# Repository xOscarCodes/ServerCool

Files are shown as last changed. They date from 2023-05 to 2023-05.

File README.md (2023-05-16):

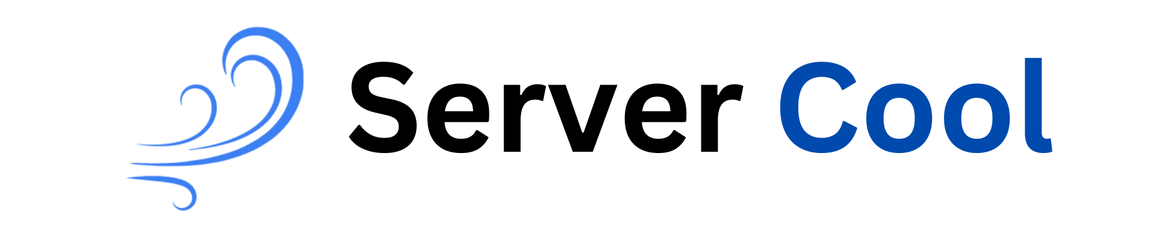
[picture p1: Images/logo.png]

# Server Cool
<p align="justify">The ServerCool interface offers a wide range of functionalities to users, who must authenticate themselves on the login page to gain access. Unauthorized use restricted from accessing information or controlling any features. One notable feature is the ability to monitor real-time temperature readings of both the server rooms and air conditioners on a single page, promoting transparency.</p>
<p align="justify">The platform also provides statistical analysis capabilities, offering line, bar, and area charts for analyzing past data. Furthermore, users can export the data in their desired format. All user actions are logged in the Audit logs, ensuring accountability and tracking.</p>
<p align="justify">A notable feature is the software's capability to switch between manual and automatic configuration. This is achieved through the utilization of neural networks for system automation. Specifically, a feedforward fully connected neural network, also known as a multi-layer perceptron (MLP), is trained to predict air conditioner temperature and fan speed based on the current room temperature. The predictions are updated every 10 minutes and published on MQTT to the designated node. Additionally, the neural network is retrained every 24 hours.</p>
<p align="justify">The MLP consists of four layers: three hidden layers and one output layer. The hidden layers employ the rectified linear unit (ReLU) as the activation function, while the output layer utilizes linear activation. The network is trained using mean squared error (MSE) loss and the Adam optimizer. This type of neural network is powerful and versatile, capable of learning complex non-linear relationships between input and output data.</p>
<p align="justify">To ensure data privacy, the audit logs, which contain the login information of users, are automatically removed from the database and the interface on the 21st of every month.</p>
<p align="justify">Another feature allows users to decode infrared (IR) signals from an air conditioner remote using an IR receiver and store the dataset in the Node. These stored signals can then be transmitted to the air conditioner's IR receiver, enabling users to activate specific commands. The transmission frequency can be adjusted to accommodate various appliances. This functionality provides a convenient and efficient method for remotely controlling the air conditioning system and managing the server room's temperature.</p>

#### Deployment Documentation: [Deployment](./Documentation/Documentation.md)

## Tech Stack
### Front-end
- HTML
- CSS
- EJS
- SCSS
- Highcharts
- Bootstrap

### Back-end
- Node js
- Express
- MongoDB

### Hardware
- ESP32
- DS18B20 Waterproof Digital Thermometer Sensor Probe
- Hi-Link 5V 0.6A AC-DC Power Converter
- Hi-Link 12V 5W Power Module
- Original JHD 20Ã—4 character LCD Display with Blue Backlight
- 12V Police Siren
- TSOP 1838B small
- IR Blaster
- ENC28J60 Ethernet LAN Module
- 5 Volt Relay 
- BC547 Transistor 
- LEDs - RED and GREEN

### Automation
- Python

### Other
- Docker
- Mosquito MQTT

## License
[MIT](https://choosealicense.com/licenses/mit/)

## Authors
- [@xOscarCodes](https://github.com/xOscarCodes)
- [@Aadi3333](https://github.com/Aadi3333)
- [@harshdeep-s](https://github.com/harshdeep-s)
- [@ishaan2307](https://github.com/ishaan2307)
- [@kanishkjain0263](https://github.com/kanishkjain0263)
- [@XQuestCode](https://github.com/XQuestCode)
- [@Yohjit-2910](https://github.com/Yohjit-2910)

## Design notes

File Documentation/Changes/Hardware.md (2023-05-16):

**Git clone the entire repository**
```bash
git clone https://github.com/xOscarCodes/ServerCool.git
```

**Change directory**
```bash
cd /ESP/ServerProject/src
```

**Change `ID` and `LOC`**
```c++
const String nodeId = "ID";
const String location = "LOC";
```

**Change IP Address**
```c++
String domain_name_str = "<MQTT-BROKER-IP-ADDRESS>";
```

Replace `<MQTT-BROKER-IP-ADDRESS>` with IP Address of MQTT Broker

**Change username and password**
```c++
  while (!client.connect("serverESP32", "<USERNAME>", "<PASSWORD>"))
  {
    Serial.print(".");
    Ethernet.init(5);
    if (Ethernet.begin(mac) == 0)
    {
      Serial.println("Failed");
    }
    Serial.print("IP Address   : ");
    Serial.println(Ethernet.localIP());
  }
```

Replace `<USERNAME>` and `<PASSWORD>` with correct MQTT credentials.

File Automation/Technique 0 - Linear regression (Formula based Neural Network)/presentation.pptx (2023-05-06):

## Machine Learning Algorithms :

(whatever I learnt in past 3 weeks)
BY- DEVYASH PARIHAR
2016A7PS0066P

## Regression: 1).Linear Regression 2).Polynomial Regression Classification: 1).Logistic Regression 2).K-Nearest Neighbors(K-NN) 3).Support Vector Machine

## Linear Regression:

- Simple linear regression is useful for finding relationship between two continuous variables. One is predictor or independent variable and other is response or dependent variable.
- Examples:
a).Years of Experience vs Salary
b). Nos of hours studied vs Marks obtained.

## Sample dataset:

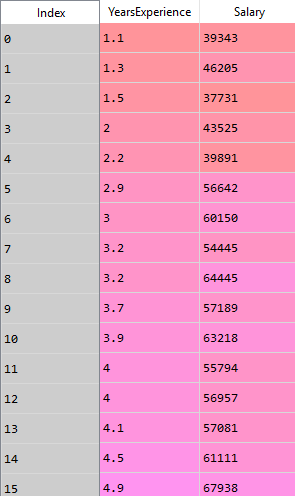
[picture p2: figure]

## Plotting the training set, we obtain a straight line in case of simple linear regression as shown below.

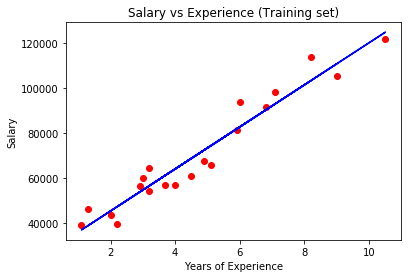
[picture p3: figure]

## Polynomial Regression:

- Polynomial regression is a form of regression analysis in which the relationship between the independent variable x and the dependent variable y is modelled as an nth degree polynomial in x.
- The kth order polynomial model in one variable is given by
y=a0 + a1*x + a2*x*x + a3*x*x*x + ……… (ak)*(x^k)

## Sample dataset:

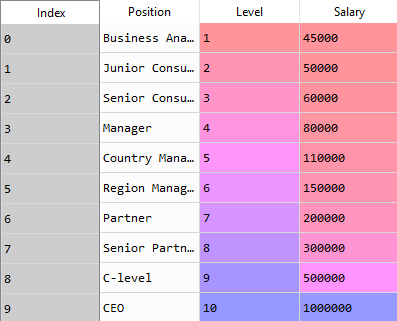
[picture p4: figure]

## Curve fits the dataset very precisely here in the case of polynomial regression.

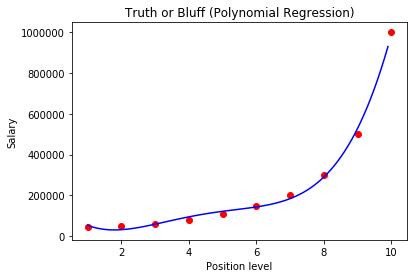
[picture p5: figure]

## Logistic Regression:

- It is the go-to method for binary classification problems (problems with two class values).
- The two possible dependent variable values are often labelled as "0" and "1", which represent outcomes such as pass/fail, win/lose, alive/dead or healthy/sick.

## Sample dataset:

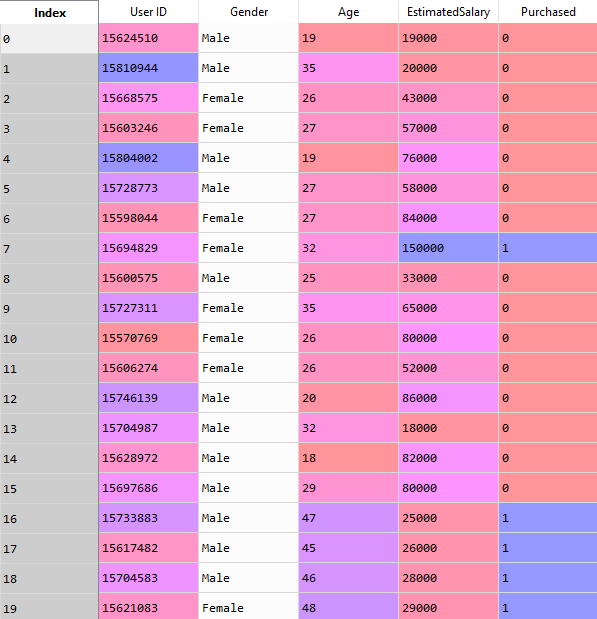
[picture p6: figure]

## Two separate regions got formed.

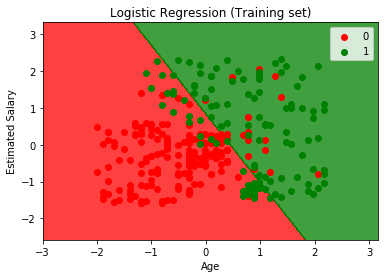
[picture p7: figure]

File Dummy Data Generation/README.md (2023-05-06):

# Generate Dummy Data
---
This directory includes the files to generated dummy data for testing.

## Changing 'COM Port' and 'Baud Rate'
---
#### Cloning the repo
```bash 
git clone https://github.com/xOscarCodes/IoT-Application-Development.git
```

#### Open two terminals and Change to the directory to 'Dummy Data Generation' directory 
```bash
cd .\IoT-Application-Development\
```

#### Command in Terminal 2
```bash
cd .\arduino\
```

#### Open any code editor 
```bash
code .
```

#### Make changes to the code
Change `path`  and `baudeRate` value to change `COM PORT` and `Baud Rate`  
```javascript
const port = new SerialPort({
    path: 'COM4',   // Change the COM port as required 
    baudRate: 9600  // Change the Baude Rate as required
})
```

Make sure that the bade rate matches with the baud rate from the Arduino code
```c++
	Serial.begin(9600);
```

## Run Locally
---

#### Open two terminals and Change to the directory to 'Dummy Data Generation' directory 
```bash
cd .\IoT-Application-Development\
```

```bash
cd '.\Dummy Data Generation\'
```
 
##### Command in Terminal 1
```bash
cd .\MQTT-API\
```

###### Start the server
```bash 
npm start
```

##### Command in Terminal 2
```bash
cd .\arduino\
```

###### Start the server
```bash
npm start
```

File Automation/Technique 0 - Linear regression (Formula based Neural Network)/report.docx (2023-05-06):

# PART 1:

# INTRODUCTION TO IDS INFOTECH:

Established in 1989, IDS Infotech Ltd. (IDS), has been a preferred Business Process Management and Software Solution provider to Fortune 500 companies and AM100 law firms worldwide for over two decades. A team of over 1,000 trained and skilled professionals, work round-the-clock to deliver quality solutions such as patent research and analytics, technology solutions, content management, engineering design and manufacturing support, physician practice management, eDiscovery and paralegal support, technical help-desk and other industry specific back-office processes. With various delivery centers in North India, IDS has multiple front-end offices globally, including US, UK and the Netherlands.

Legal Services- IDS- Legal has been a worldwide leader in providing legal support services since 1999. We provide Fortune 1000 companies and AM250 Law Firms with an elite group of professionals providing e-Discovery and Paralegal services. (http://www.ids-legal.com/)

Engineering Services- Inde Dutch Engineering & Aerospace Services Limited ("IDEAS"), an AS9100 Rev D certified company, is a leading engineering solutions provider catering to customers in the Aerospace, Semiconductors, Automotive, Machinery, and Affiliated Industry segments. (http://www.ideasengg.com/)

Software Services- With a team of 100+ Software Engineers, IDS provides its customers with customized software solutions, supporting the end to end cycle of product development. We offer an exceedingly productive fusion of business and technological expertise utilizing our in-house domain experts. (http://ids-technologies.in/)

Content Publishing And Management Service - The Content Management and Publishing Services Group (CMPSG) at IDS Infotech Ltd., specializes in delivering customized, technology driven data capture, data conversion, e-publishing, pre press and editorial solutions. (http://cmp.idsil.com/)

Patent Research And Analytics- IDS-IP offers a suite of Patent Research and Analytics Services in creation, protection and monetization of patent rights. Our processes are specially designed and tailored to provide patent protection. (http://www.ids-ip.com/)

HealthCare Services- IDS-Healthcare is a specialized team of professionals providing a gamut of Healthcare services to Hospitals, CROs, Medical Management Companies, Insurance providers, etc. worldwide. (http://www.idsargus.com/)

Environment Health And Safety Services- IDS has been providing (M)SDS services to Environment, Health and Safety (EH&S) compliance and information management services companies in USA and Canada for over eight years. (http://idsil.com/environment.php)

Medical Scribe- At IDS, we offer virtual scribe services to US doctors with marvels of technology to stream live patient visits to our HIPAA compliant facilities , whereby IDS Medical Scribes undertake real time updates of US hospital EHRs. (https://medicalscribe.idsil.com/)

# PART 2:

# SUPERVISED MACHINE LEARNING:

1). Regression:

a). Simple Linear Regression- Simple linear regression is useful for finding relationship between two continuous variables. One is predictor or independent variable and other is response or dependent variable.

- Example:


(Years of Experience vs Salary dataset)


(Plotting the training set)

b). Polynomial Regression- Polynomial regression is a form of regression analysis in which the relationship between the independent variable x and the dependent variable y is modelled as a nth degree polynomial in x.

The kth order polynomial model in one variable is given by

y=a0 + a1*x + a2*x*x + a3*x*x*x + ……… (ak)*(x^k)

Consider the dataset given below.


Curve fits the dataset very precisely here in the case of polynomial regression.


2). Classification:

a). Logistic Regression- It is the go-to method for binary classification problems (problems with two class values).

The two possible dependent variable values are often labelled as "0" and "1", which represent outcomes such as pass/fail, win/lose, alive/dead or healthy/sick.


The above dataset is used to make the machine learn and thus to predict whether a customer is going to buy the product or not based on the variables such as his/her salary, age etc.


So, two separate regions got classified. However not all the predictions are correct as some of the green points are in the red region while some of the red points are in green region. Still, it’s a good model to predict whether the customer is going to buy the product or not.

b). K-Nearest Neighbors(K-NN)- KNN is a non-parametric, lazy learning algorithm. Its purpose is to use a database in which the data points are separated into several classes to predict the classification of a new sample point.

We are going to plot the previous dataset using this algorithm this time.

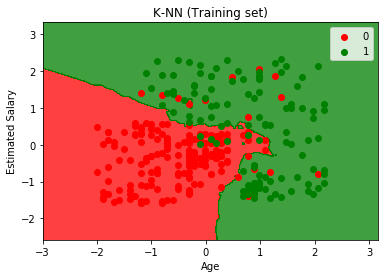
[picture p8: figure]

This time the boundary is not a straight line as it was in logistic regression and therefore it is more accurate in predicting the dependent variable.

c). Support Vector Machine- A Support Vector Machine (SVM) is a discriminative classifier formally defined by a separating hyperplane. In other words, given labeled training data (supervised learning), the algorithm outputs an optimal hyperplane which categorizes new examples. In two-dimensional space this hyperplane is a line dividing a plane in two parts where in each class lay in either side.

We are again using the earlier dataset to see how this algorithm predicts or performs in comparison to others.

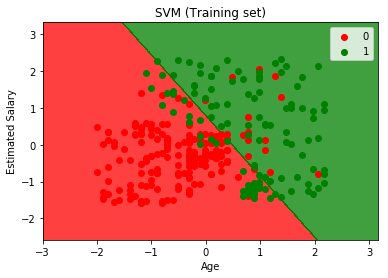
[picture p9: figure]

It also makes a line dividing the plane in two regions just like the logistic regression. However, in the case of logistic regression the decision boundary needs not to be a straight line always. Its shape can vary.

# PART 3:

# ANALYSIS OF TEMPERATURE AND HUMIDITY AT COMPANY’S OFFICE OF LAST TWO YEARS:

INTRODUCTION:

We have been shared a file that contains each day’s temperature and humidity entries at the company’s office for the last 2 years and we are supposed to find or establish a relationship between the temperature/humidity and the time of the day it was recorded at. Here is a sample of the dataset we had been given. It has the following variable as columns:

a) ID
b) Temperature
c) Humidity
d) Date and time

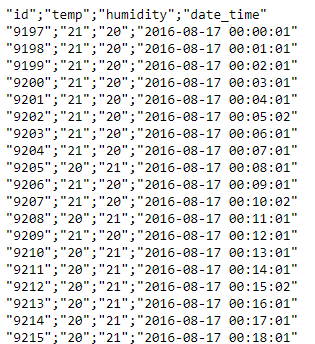
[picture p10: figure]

PROGRESS:

Till now, we have done the data preprocessing part completely. i.e. we made a table with the above listed variables as its columns.

The next thing we need to do is to make a model using one of the various machine learning algorithms so as to find the relationship if there exists any. Attached below is the preprocessed data in the form of a table.

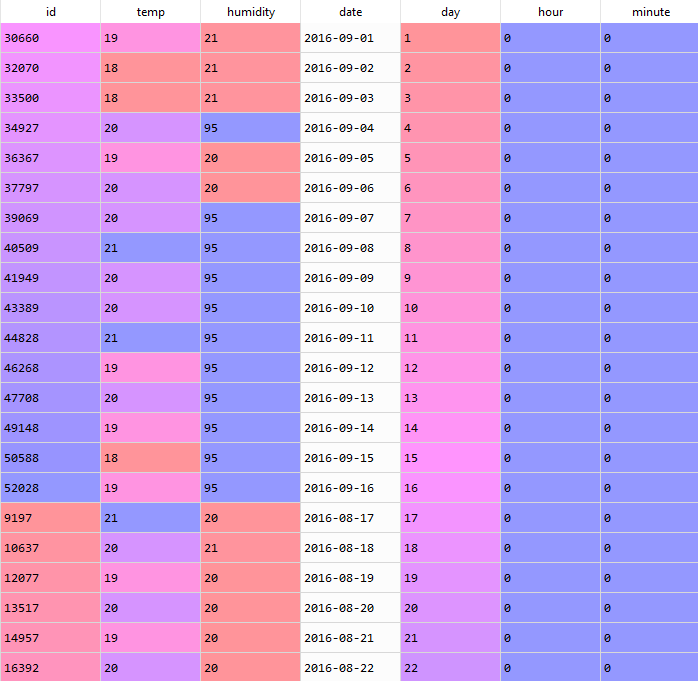
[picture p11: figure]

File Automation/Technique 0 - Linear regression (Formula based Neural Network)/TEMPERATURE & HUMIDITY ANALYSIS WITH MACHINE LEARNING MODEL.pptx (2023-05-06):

## TEMPERATURE & HUMIDITY ANALYSIS WITH MACHINE LEARNING MODEL

UNDER GUIDANCE OF: MR JAY RAM SINGH (TECHNICAL TEAM MANAGER)
MS DEEPTI KUMARI (HR AT CHANDIGARH CENTER)
MS AMRITA KAPOOR BEDI (ASSISTANT MANAGER HR,CORPORATE)
BY: DEVYASH PARIHAR (2016A7PS0066P)
SAI PUNEETH (2016A7PS0059H)

## PROJECT DESCRIPTION

DATASET:

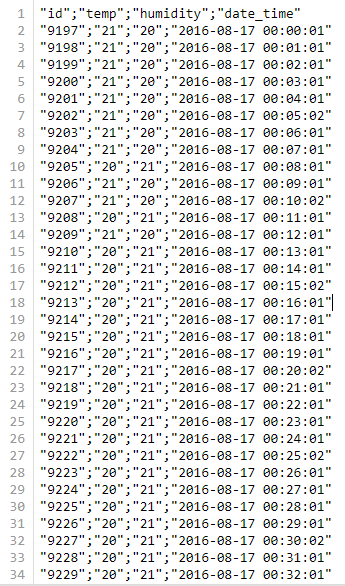
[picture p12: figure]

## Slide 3

- The dataset has 8,21,692 rows.
- Contains each minute’s temperature and humidity recordings at Mohali’s server room.
- Ranges from 2016-08-17 to 2018-05-24.
- What can we obtain from this data ? (Objective)

## Data preprocessing:

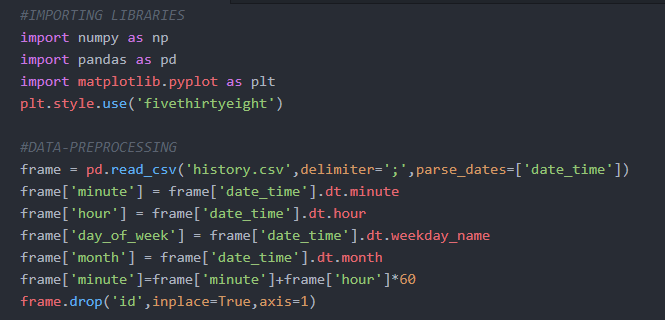
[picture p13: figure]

## DATAFRAME:

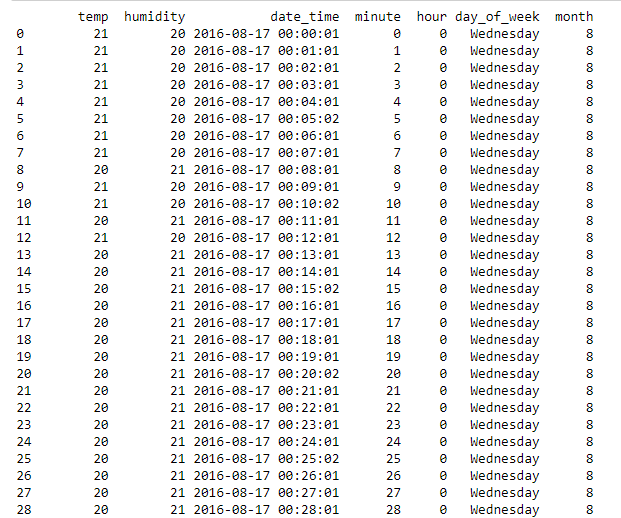
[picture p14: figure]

## Temp vs time of the day graph for the first day of the dataset :

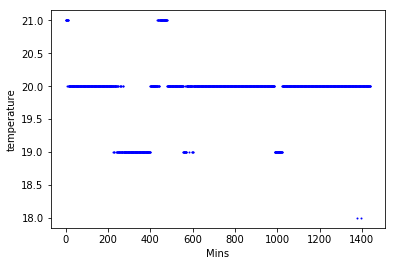
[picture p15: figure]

## Temp vs time of the day graph for the second day of the dataset :

## MAKING SEPARATE DATAFRAMES FOR DIFFERENT DAYS OF A WEEK:

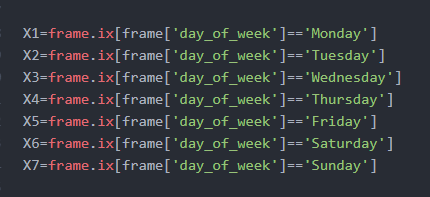
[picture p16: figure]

## X1 :

## Plotting avg Temp vs time of the day for different days of the week:

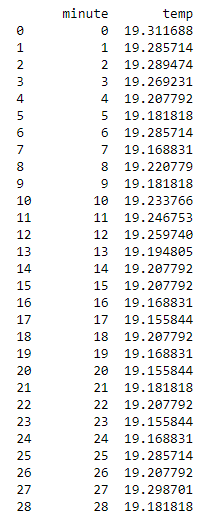
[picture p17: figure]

## Monday:

## Tuesday:

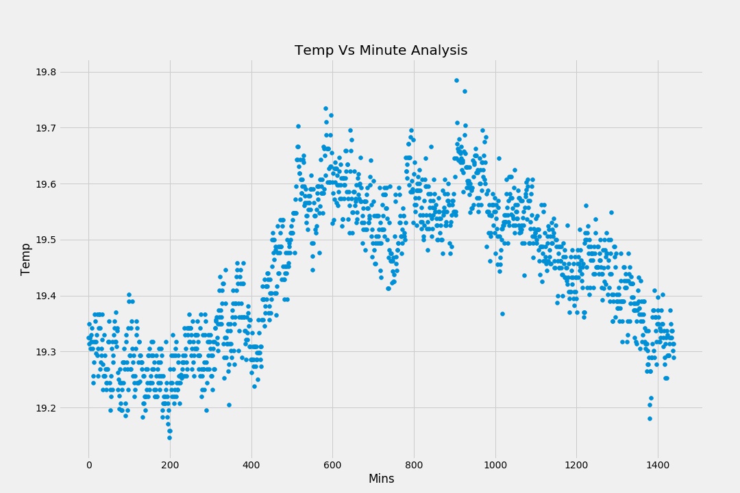
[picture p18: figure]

## Wednesday:

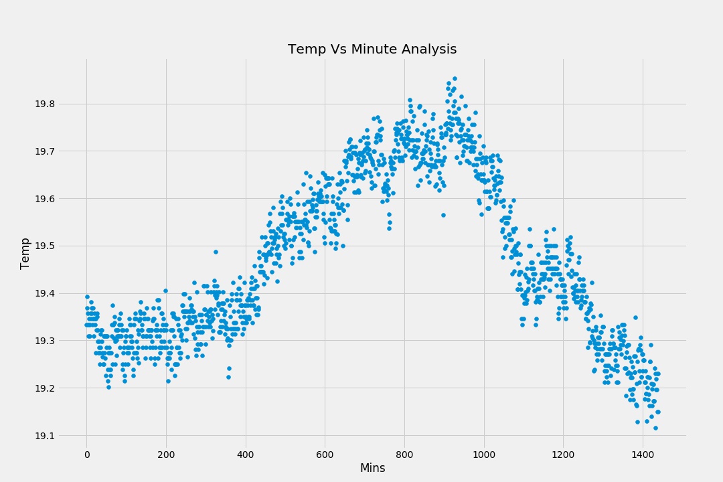
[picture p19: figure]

## Thursday:

## Friday:

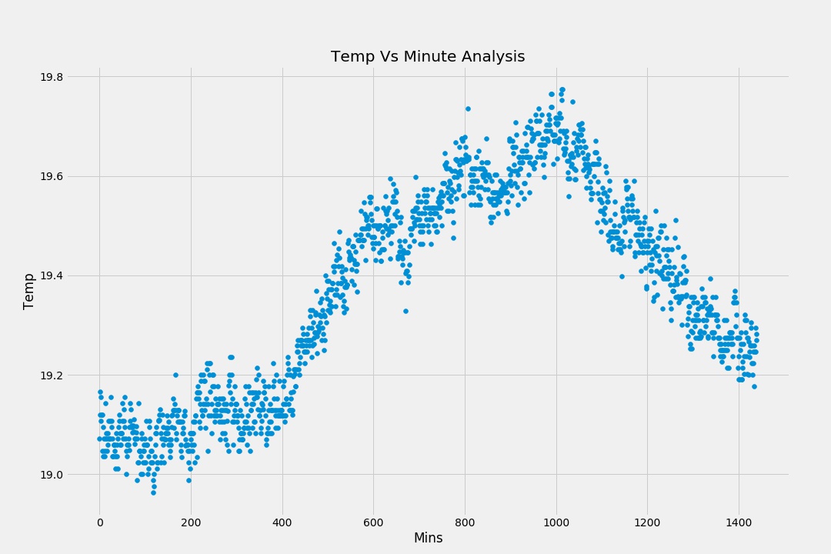
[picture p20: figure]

## Saturday:

## Sunday:

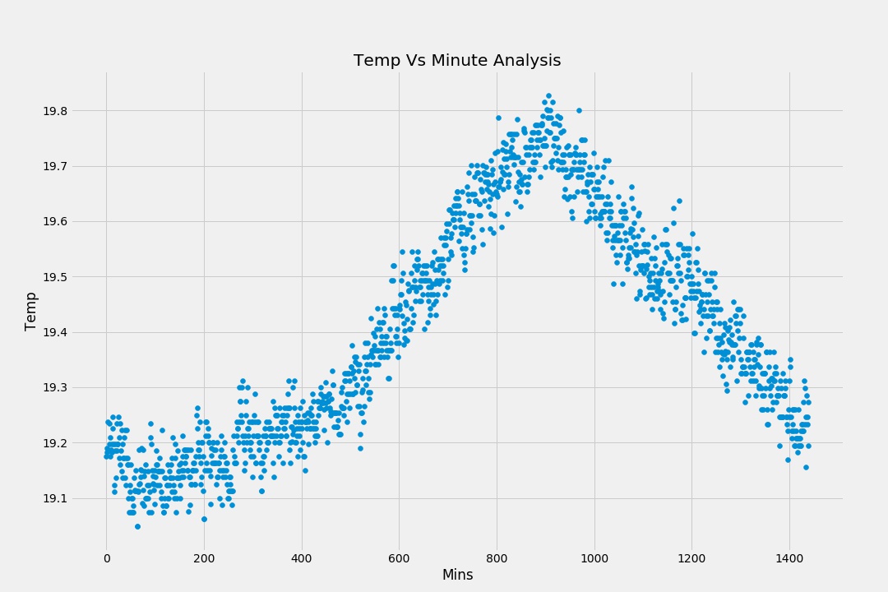
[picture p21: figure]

## General day:

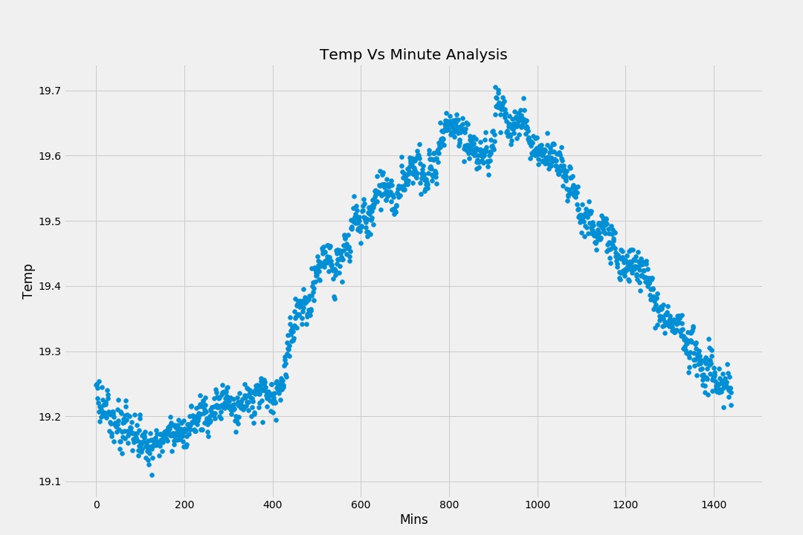
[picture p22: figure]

## General day (hour wise):

## Observations:

- Plots are now smoother.
- A polynomial relationship is observed in each of the plots.
- Thus, a polynomial regression model can be built.

## Building polynomial regression model:

- Preparing dataset and training:

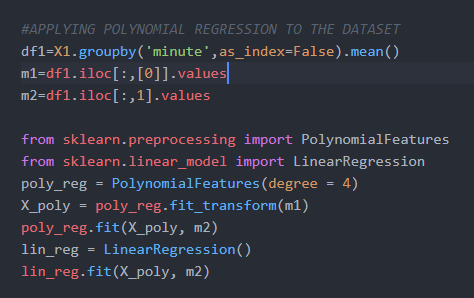
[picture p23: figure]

## Visualization:

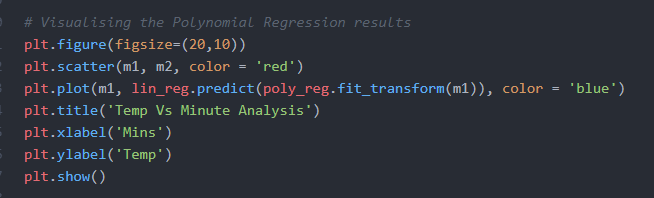
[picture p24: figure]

## Monday:

## Tuesday:

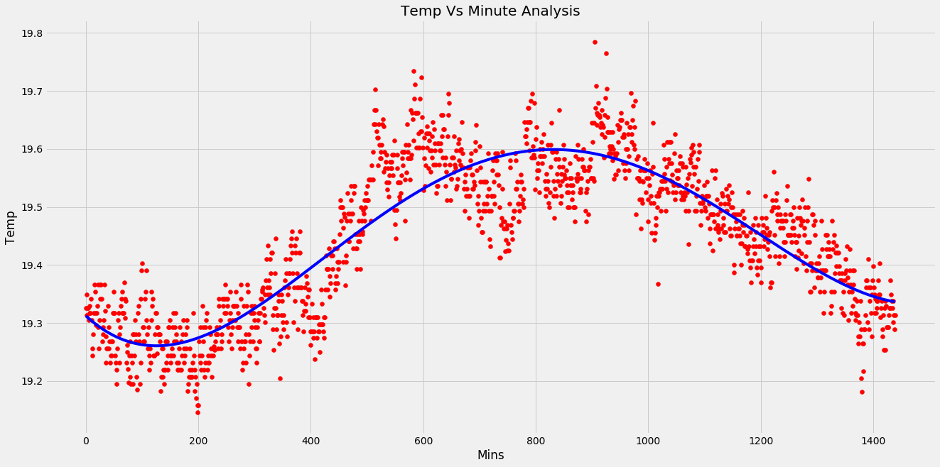
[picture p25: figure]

## Wednesday:


## Thursday:

## Friday:


## Saturday:

## Sunday:


## General day:


## General day(hour):

## Humidity analysis:


## Monday:


## Tuesday:

## Wednesday :


## Thursday:

## Friday:


## Saturday:


## Sunday:

## Month-wise:


## CONCLUSION:

- A polynomial model got developed that can be used to predict temperature values for a given time of a given date and it can be used by the company for future predictions.
- However in the case of humidity, we were not able to spot any particular relationship between the time of the day and humidity value.

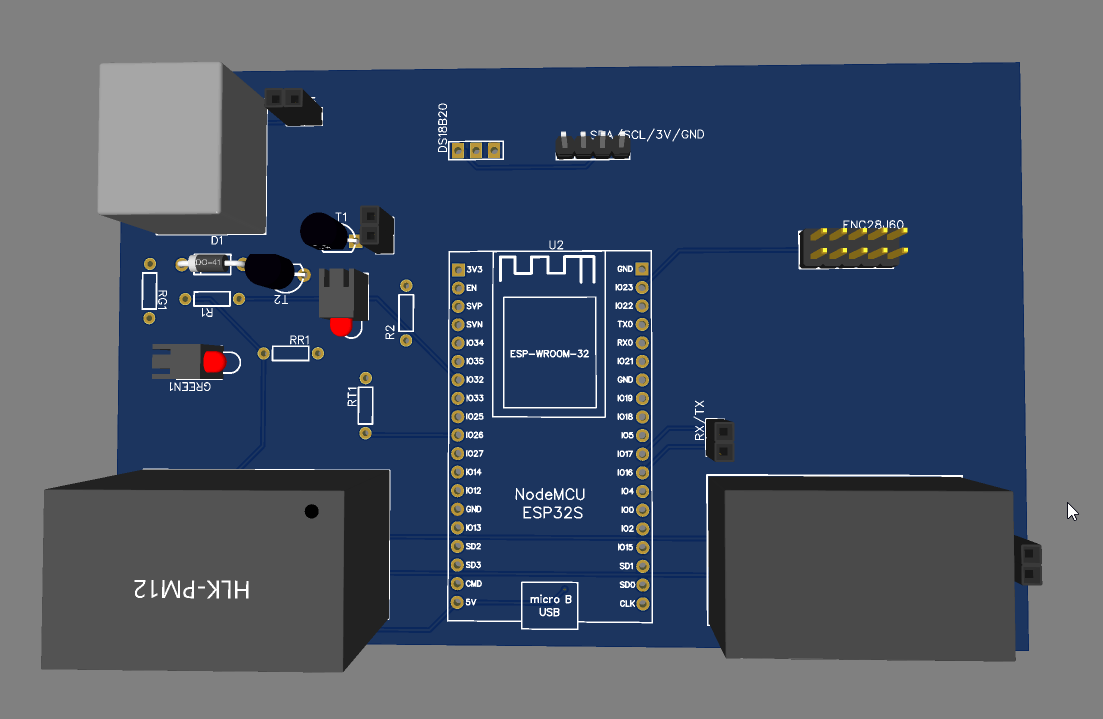
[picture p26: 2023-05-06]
ESP/PCB Files/Images/easyeda_UbSFG7FHMJ.png

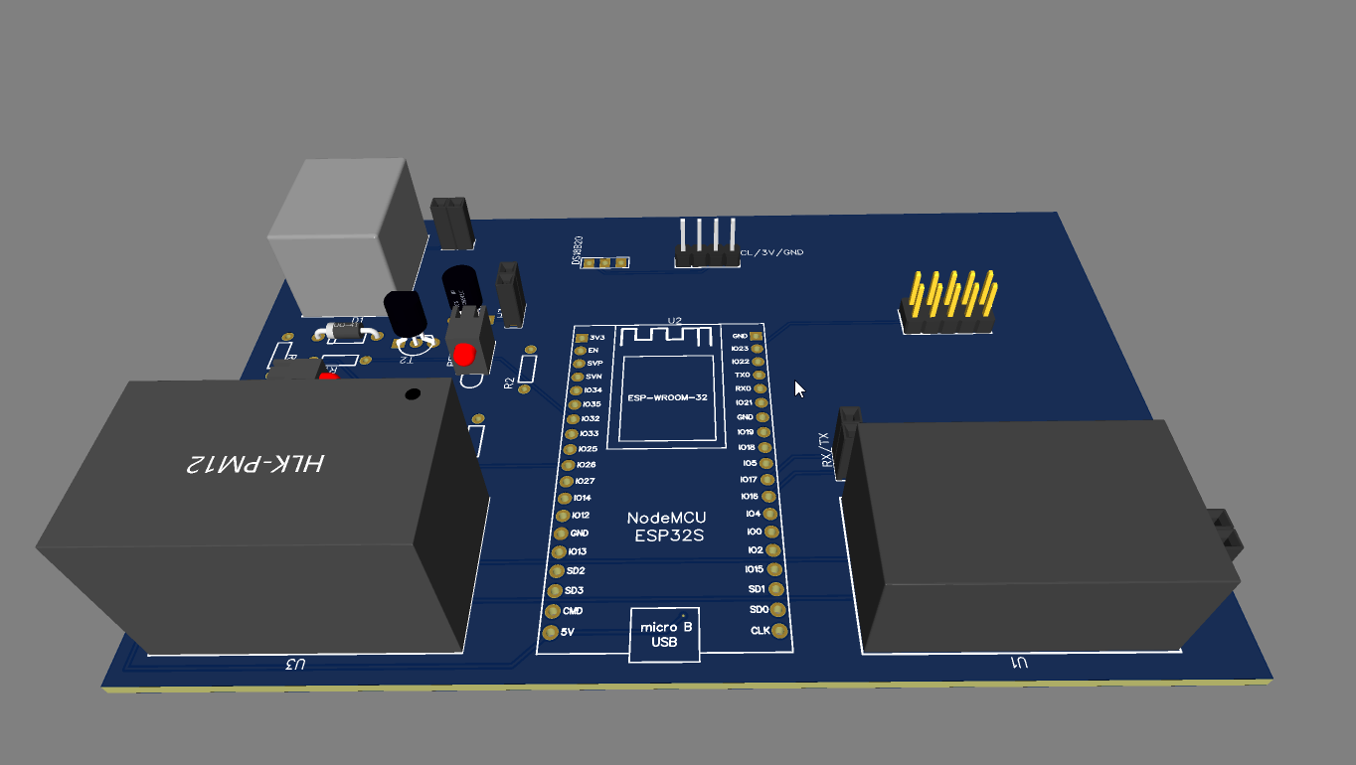
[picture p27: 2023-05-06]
ESP/PCB Files/Images/easyeda_Jt8ZsACOgd.png

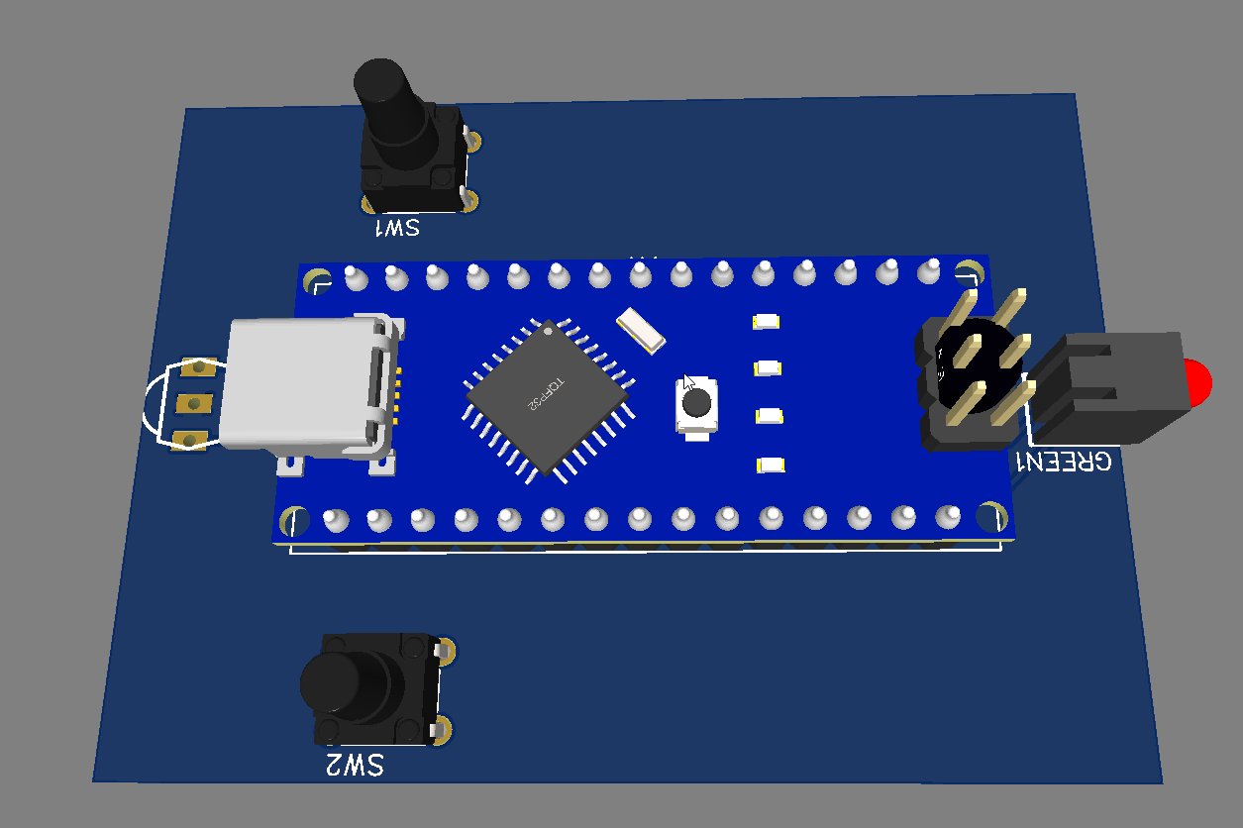
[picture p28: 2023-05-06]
ESP/PCB Files/Images/easyeda_o0bEYAMk3R.png

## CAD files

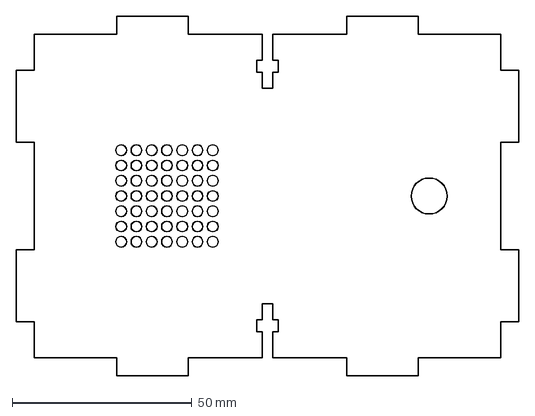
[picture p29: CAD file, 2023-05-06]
CAD Files For Node Box/DFX Files/Side Right.dxf
140.0 x 100.0 mm

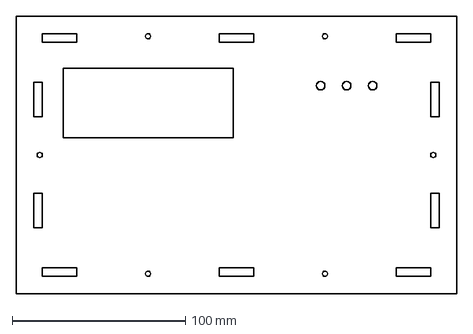
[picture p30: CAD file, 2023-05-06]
CAD Files For Node Box/DFX Files/Front Plate.dxf
254.0 x 160.0 mm

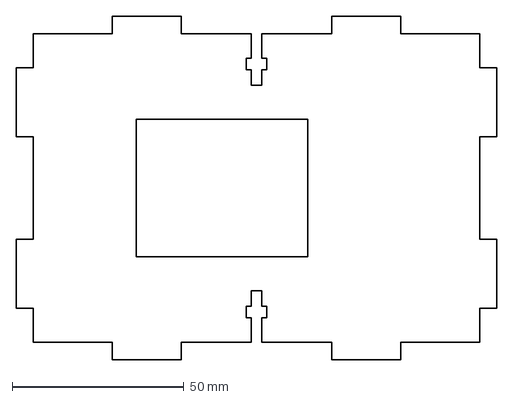
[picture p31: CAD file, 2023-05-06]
CAD Files For Node Box/DFX Files/Side Left.dxf
140.0 x 100.0 mm

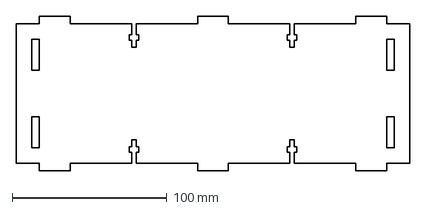
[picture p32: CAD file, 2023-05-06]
CAD Files For Node Box/DFX Files/Bottom Plate.dxf
254.0 x 100.0 mm

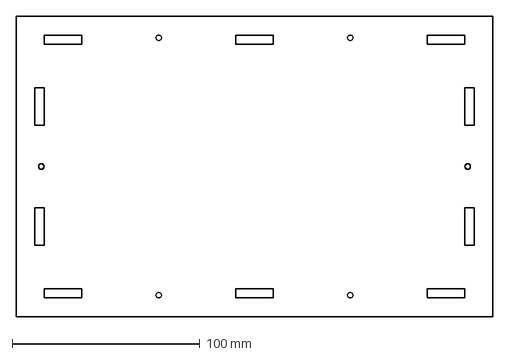
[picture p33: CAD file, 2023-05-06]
CAD Files For Node Box/DFX Files/Base Plate.dxf
254.0 x 160.0 mm

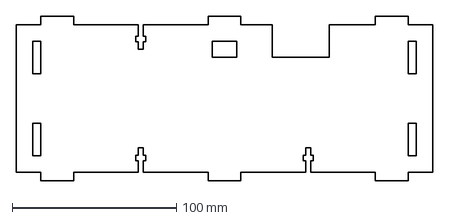
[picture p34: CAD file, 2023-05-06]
CAD Files For Node Box/DFX Files/Top Plate.dxf
254.0 x 100.0 mm

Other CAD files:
CAD Files For Node Box/Fusion 360/Base Plate v10.f3d
CAD Files For Node Box/Fusion 360/Bottom Plate v4.f3d
CAD Files For Node Box/Fusion 360/Front Plate v2.f3d
CAD Files For Node Box/Fusion 360/Side Plate Left Siren v8.f3d
CAD Files For Node Box/Fusion 360/Side Plate Right Fan v9.f3d
CAD Files For Node Box/Fusion 360/Top Plate LAN v4.f3d

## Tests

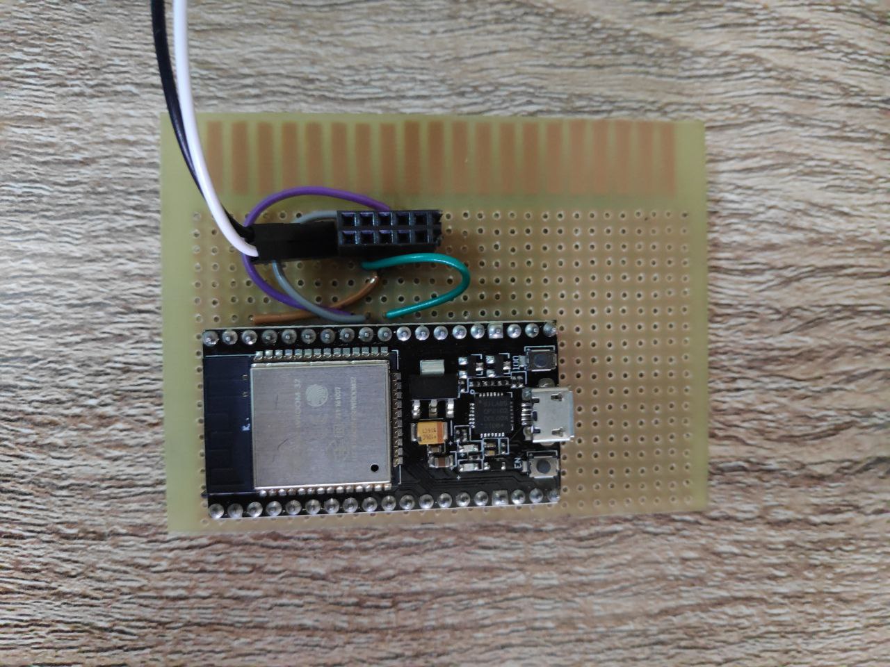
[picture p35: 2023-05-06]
ESP/Images/Test Hardware/Without Module.jpg

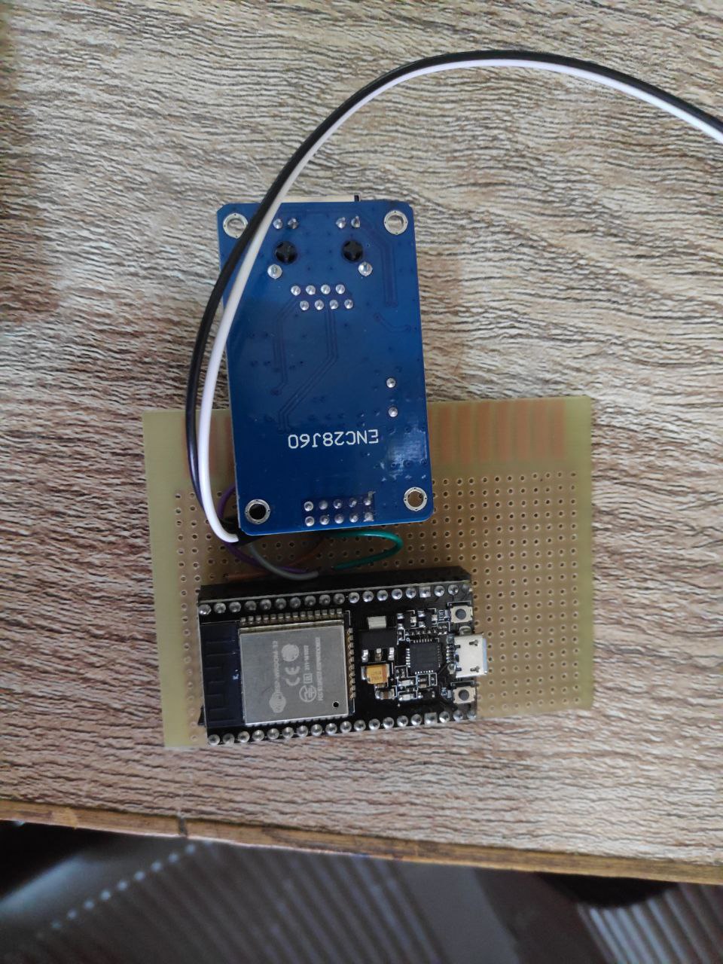
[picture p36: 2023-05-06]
ESP/Images/Test Hardware/With Module.jpg

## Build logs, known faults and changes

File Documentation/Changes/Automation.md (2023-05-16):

**Git clone the entire repository**

```bash
git clone https://github.com/xOscarCodes/ServerCool.git
```

**Change directory**

```bash
cd /Automation/Final\ File\ Setup/
```

**Change `audit_deletion.py` and `server_room_auto.py`**
Change `connection_string`
```python
connection_string = "mongodb://<USERNAME>:<PASSWORD>@<IP>:<PORT>/?authSource=admin"
```

Replace `<USERNAME>` and `<PASSWORD>` with correct MongoDB credentials

Change MQTT credentials
```python
username = "<MQTT-USERNAME>"
password = "<MQTT-PASSWORD>"
```

Replace `<MQTT-USERNAME>` and `<MQTT-PASSWORD>` with correct MQTT credentials

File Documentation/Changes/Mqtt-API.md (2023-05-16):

**Git clone the entire repository**

```bash
git clone https://github.com/xOscarCodes/ServerCool.git
```

**Change directory**

```bash
cd /website/mqtt/config
```

**Make changes in 'keys.js' file**

```javascript
module.exports = {
    MongoURI:"mongodb://<MONGODB-USERNAME>:<MONGODB-PASSWORD>@<IP>:<PORT-Default-port:27017>/serverCool",
    mqttURI: "mqtt://<IP>:<PORT>", // HOSTNAME:PORT if using host of the broker
    username: '<MQTT-USERNAME>',
    password: '<MQTT-PASSWORD>',
    user: '<MONGODB-USERNAME>',
    pass: '<MONGODB-PASSWORD>',
    mqttPort: 1883
}
```

Replace `MONGODB-USERNAME`  and `MONGODB-PASSWORD` with authentication details of MongoDB database. Also change `IP` and `PORT` number. Mostly, `27017` is default port number. 
Replace `MQTT-USERNAME` and `MQTT-PASSWORD` with mqtt authentication details.

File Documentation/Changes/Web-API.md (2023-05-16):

**Git clone the entire repository**

```bash
git clone https://github.com/xOscarCodes/ServerCool.git
```

**Change directory**

```bash
cd /website/api/config
```

**Make changes in 'keys.js' file**

```javascript
module.exports = {
    MongoURI:"mongodb://<USERNAME>:<PASSWORD>@<IP>:<PORT-Default-port:27017>/serverCool",
    user: '<USERNAME>',
    pass: '<PASSWORD>',
}
```

Replace `USERNAME`  and `PASSWORD` with authentication details of MongoDB database. Also change `IP` and `PORT` number. Mostly, `27017` is default port number.

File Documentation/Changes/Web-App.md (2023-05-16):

**Git clone the entire repository**

```bash
git clone https://github.com/xOscarCodes/ServerCool.git
```

**Change directory**

```bash
cd /website/mqtt/config
```

**Make changes in 'keys.js' file**

```javascript
module.exports = {
    MongoURI:"mongodb://<MONGODB-USERNAME>:<MONGODB-PASSWORD>@<IP>:<PORT-Default-port:27017>/serverCool",
    mqttURI: "mqtt://<IP>:<PORT>", // HOSTNAME:PORT if using host of the broker
    username: '<MQTT-USERNAME>',
    password: '<MQTT-PASSWORD>',
    user: '<MONGODB-USERNAME>',
    pass: '<MONGODB-PASSWORD>',
    mqttPort: 1883
}
```

Replace `MONGODB-USERNAME`  and `MONGODB-PASSWORD` with authentication details of MongoDB database. Also change `IP` and `PORT` number. Mostly, `27017` is default port number. 
Replace `MQTT-USERNAME` and `MQTT-PASSWORD` with mqtt authentication details.

**Change directory**
```bash
cd /website/web/public
```

**Make changes to `statistics.html` file**
```javascript
const API_URL = 'http://<API-IP>:5000/api/nodeData';
```

Replace `<API-IP>` with actual IP of the API

**Change directory**
```bash
cd /website/web/public/Resources/script
```

**Make changes to `show-audit.js`, `show-nodes.js` and `ui.js` script file**
```javascript
const API_URL = 'http://<API-IP>:5000/api/nodeData';
```

Replace `<API-IP>` with actual IP of the API

**Make changes to `ui.js` script file**
```javascript
let mqttURI = 'http://<MQTT-API-IP>:5001/send-command';
```

Replace `<MQTT-API-IP>` with actual IP of the MQTT Broker

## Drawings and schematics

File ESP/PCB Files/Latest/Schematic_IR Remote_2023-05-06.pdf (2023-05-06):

## TSOP

## Buttons

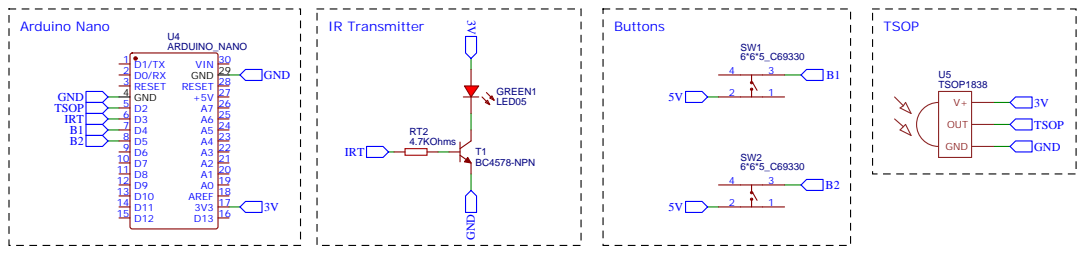
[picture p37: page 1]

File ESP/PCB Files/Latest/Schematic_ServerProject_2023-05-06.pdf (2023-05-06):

## Nodemcu 32S

ESP32 | Headers | 5V Power Supply

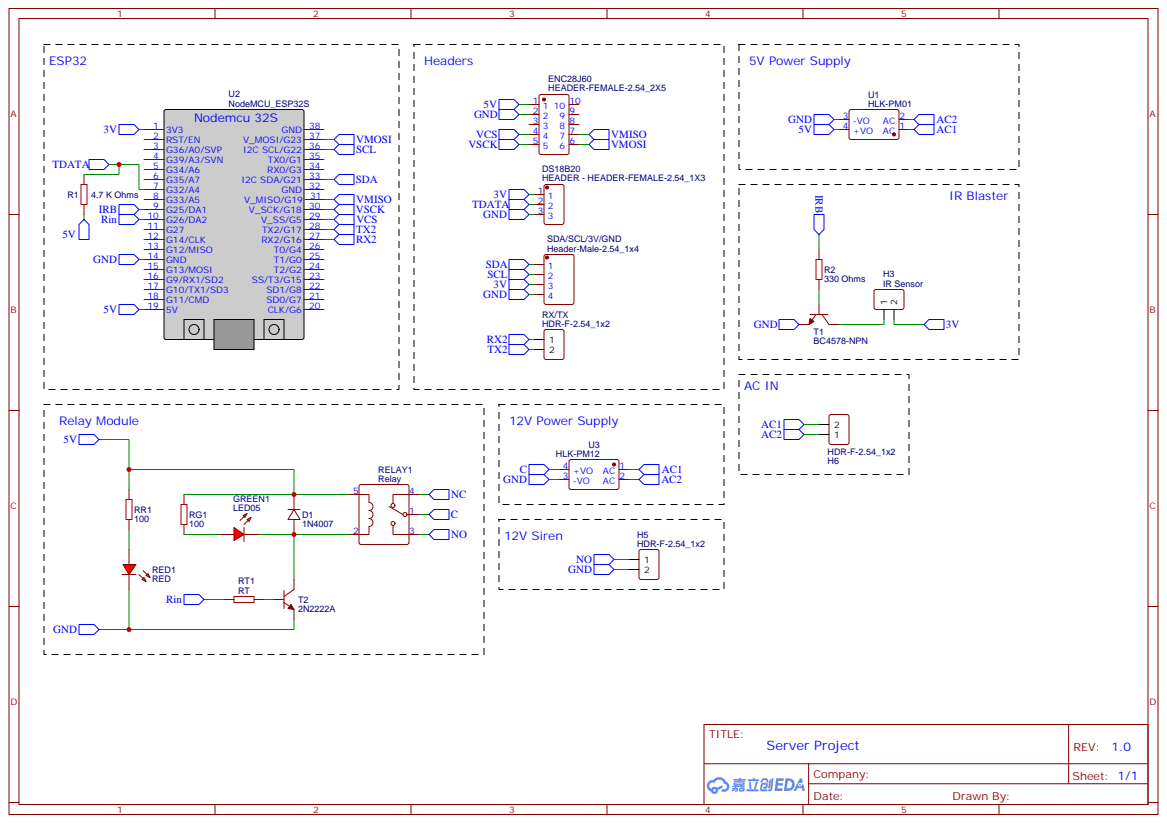
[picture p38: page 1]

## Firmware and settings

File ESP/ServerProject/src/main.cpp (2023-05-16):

/**
 * @file main.cpp
 * @authors Charanpreet Singh
 *          Aaditya Mahla
 *          Harshdeep Singh
 *          Ishaan Gupts
 * @brief Project Code file
 * @details Project ServoCool
 * @version 1.0
 * @copyright Copyright (c) 2023
 */
#include <SPI.h>
#include <PubSubClient.h>
#include <UIPEthernet.h>
#include <OneWire.h>
#include <DallasTemperature.h>
#include <IRsend.h>
#include <LiquidCrystal_I2C.h>

const String nodeId = "ID";
const String location = "LOC";
const int oneWireBus = 32;
const int irBlasterPin = 25;
const int siren = 26;

OneWire oneWire(oneWireBus);

DallasTemperature sensors(&oneWire);

IRsend irsend(25);

LiquidCrystal_I2C lcd(0x27, 20, 4); // set the LCD address to 0x27 for a 16 chars and 2 line display

byte mac[] = {0x0E, 0x96, 0x03, 0x38, 0x94, 0x92};
EthernetClient eclient;
PubSubClient client(eclient);

unsigned long lastMillis = 0;

String tempC = "";
float temperatureC = 0;
char temp[50];

String ACtemp = "";

const uint16_t port_number = 1883;

String domain_name_str = "<MQTT-BROKER-IP-ADDRESS>";
char domain_name[50];

String publish_topic_str = "/node/temp" + nodeId;
char publish_topic[50];

String subscribe_topic_str = "/node/config/" + nodeId;
char subscribe_topic[50];
// const char *subconfigIP = "/node/config/ip/" + nodeId;

// ---- COMMANDS ----
uint16_t off[] = {3868, 1356, 712, 1044, 708, 1044, 708, 312, 720, 328, 704, 340, 696, 1044, 708, 324, 708, 324, 712, 1044, 708, 1044, 708, 324, 708, 1048, 708, 324, 708, 324, 708, 1044, 712, 1044, 708, 324, 708, 1048, 708, 1044, 708, 324, 708, 324, 708, 1044, 708, 328, 704, 328, 708, 1048, 704, 328, 708, 324, 708, 324, 708, 324, 708, 324, 708, 324, 708, 324, 712, 340, 692, 324, 704, 328, 708, 324, 708, 324, 708, 324, 708, 324, 708, 344, 692, 324, 708, 340, 692, 340, 692, 340, 692, 340, 692, 1048, 708, 336, 692, 344, 716, 1040, 712, 1040, 716, 316, 716, 316, 716, 316, 712, 320, 712, 320, 712, 324, 712, 1044, 708, 1044, 708, 1044, 708, 1044, 708, 328, 700, 332, 700, 332, 700, 336, 676, 1076, 676, 1076, 676, 356, 676, 1076, 676, 360, 672, 360, 672, 360, 672, 360, 676, 360, 672, 360, 672, 360, 672, 360, 672, 360, 676, 356, 676, 356, 676, 360, 672, 360, 672, 360, 676, 356, 676, 344, 688, 340, 692, 360, 672, 344, 684, 348, 688, 1068, 688, 344, 688, 344, 684, 360, 672, 360, 672, 360, 672, 360, 648, 388, 648, 1104, 648, 388, 644, 1108, 644, 388, 644, 388, 644, 388, 644, 388, 644, 388, 648, 388, 644, 388, 644, 388, 644, 1112, 640, 1112, 640, 392, 640, 1116, 636, 396, 640};
uint16_t low17[] = {3896, 1328, 676, 1080, 676, 1076, 672, 360, 672, 360, 672, 360, 676, 1080, 672, 360, 672, 360, 676, 1084, 668, 1084, 668, 364, 672, 1080, 672, 360, 672, 360, 672, 1080, 672, 1084, 676, 360, 672, 1080, 672, 1080, 672, 360, 668, 364, 648, 1108, 668, 364, 668, 364, 676, 1080, 672, 360, 672, 360, 672, 360, 672, 360, 672, 360, 672, 360, 672, 360, 676, 360, 672, 360, 672, 360, 672, 360, 672, 360, 676, 356, 672, 360, 672, 364, 672, 360, 672, 360, 672, 1080, 672, 364, 672, 360, 672, 1080, 672, 360, 672, 360, 676, 1080, 676, 1076, 676, 356, 676, 360, 672, 360, 672, 360, 672, 360, 672, 360, 676, 360, 672, 1080, 672, 1080, 676, 1080, 700, 332, 672, 360, 672, 360, 676, 356, 704, 332, 676, 1076, 672, 360, 676, 1076, 676, 356, 676, 360, 696, 332, 676, 360, 676, 356, 704, 328, 704, 332, 700, 332, 676, 356, 704, 328, 700, 332, 700, 332, 704, 328, 708, 328, 704, 340, 692, 328, 704, 328, 704, 328, 704, 344, 688, 344, 696, 1060, 692, 340, 692, 340, 692, 340, 716, 316, 720, 312, 720, 312, 716, 320, 716, 316, 716, 316, 716, 1040, 712, 316, 716, 1040, 712, 320, 712, 320, 712, 324, 712, 1040, 712, 320, 712, 320, 712, 1040, 712, 324, 708, 1044, 712, 1040, 712, 324, 780};
uint16_t low18[] = {3896, 1324, 648, 1112, 640, 1112, 644, 388, 644, 388, 644, 388, 644, 1108, 644, 388, 644, 388, 648, 1112, 644, 1108, 644, 388, 644, 1108, 644, 388, 644, 388, 648, 1108, 644, 1108, 648, 388, 644, 1108, 644, 1108, 668, 368, 668, 364, 644, 1108, 668, 364, 644, 388, 652, 1104, 648, 384, 672, 360, 668, 364, 668, 364, 672, 360, 672, 360, 672, 360, 676, 360, 672, 360, 672, 364, 668, 360, 672, 360, 648, 388, 668, 364, 672, 360, 672, 360, 672, 364, 668, 1084, 672, 360, 672, 360, 672, 1080, 672, 360, 700, 332, 676, 1080, 676, 1080, 672, 360, 700, 332, 672, 360, 676, 356, 700, 332, 700, 332, 704, 1052, 700, 332, 680, 1072, 704, 1052, 700, 332, 704, 328, 700, 332, 704, 328, 708, 328, 700, 1052, 704, 328, 708, 1048, 704, 328, 704, 340, 716, 316, 692, 344, 692, 344, 692, 336, 696, 336, 720, 312, 720, 312, 720, 316, 716, 316, 716, 316, 720, 316, 712, 320, 712, 320, 712, 320, 712, 320, 712, 320, 712, 320, 712, 324, 712, 1040, 712, 320, 712, 320, 712, 320, 712, 320, 712, 320, 708, 324, 708, 328, 708, 324, 708, 324, 708, 324, 708, 324, 708, 1032, 716, 332, 700, 332, 704, 328, 708, 328, 700, 332, 680, 1056, 696, 352, 680, 352, 680, 1060, 692, 1060, 692, 356, 780};
uint16_t low19[] = {3868, 1352, 716, 1044, 708, 1044, 708, 324, 712, 308, 724, 308, 724, 1040, 712, 324, 708, 324, 712, 1044, 708, 1044, 712, 324, 708, 1044, 708, 324, 708, 324, 708, 1044, 712, 1040, 712, 324, 708, 1044, 712, 1044, 708, 324, 708, 324, 708, 1044, 708, 324, 708, 324, 712, 1044, 712, 324, 708, 324, 708, 324, 708, 324, 708, 324, 708, 324, 708, 324, 712, 324, 708, 324, 708, 324, 708, 324, 708, 324, 708, 324, 708, 324, 708, 324, 712, 324, 708, 340, 692, 1044, 708, 324, 708, 324, 708, 1048, 708, 324, 704, 328, 708, 1048, 708, 1044, 708, 324, 708, 324, 708, 324, 708, 324, 708, 328, 704, 328, 708, 324, 708, 328, 704, 1048, 704, 1048, 708, 324, 708, 340, 692, 324, 708, 344, 692, 340, 692, 1044, 708, 340, 692, 1048, 704, 344, 692, 340, 692, 340, 708, 324, 716, 320, 712, 320, 712, 320, 712, 320, 712, 320, 712, 320, 712, 320, 712, 324, 712, 320, 712, 320, 712, 320, 708, 324, 708, 324, 708, 324, 708, 324, 708, 328, 708, 1044, 704, 328, 704, 328, 680, 352, 680, 352, 680, 352, 676, 360, 676, 356, 676, 356, 676, 360, 672, 1080, 672, 360, 676, 1060, 692, 356, 676, 356, 680, 356, 680, 1060, 692, 1060, 692, 1060, 692, 356, 676, 356, 676, 1064, 688, 1064, 688, 360, 748};
uint16_t low20[] = {3900, 1320, 720, 1040, 712, 1044, 708, 324, 708, 308, 724, 312, 720, 1044, 712, 304, 724, 324, 712, 1044, 712, 1044, 708, 324, 708, 1044, 708, 324, 708, 324, 708, 1044, 712, 1044, 712, 320, 712, 1044, 708, 1044, 708, 324, 708, 324, 712, 1044, 708, 320, 712, 324, 712, 1044, 708, 324, 708, 324, 708, 324, 708, 324, 708, 324, 708, 324, 708, 324, 712, 324, 708, 324, 708, 324, 708, 328, 704, 324, 708, 324, 708, 328, 704, 324, 712, 324, 708, 340, 692, 1044, 708, 340, 692, 328, 704, 1048, 704, 328, 708, 340, 696, 1044, 708, 1048, 704, 340, 692, 340, 692, 344, 712, 316, 716, 320, 712, 324, 712, 1040, 712, 1040, 712, 320, 712, 1040, 712, 320, 712, 320, 712, 324, 708, 324, 712, 324, 704, 1048, 704, 328, 704, 1048, 704, 328, 704, 328, 684, 348, 680, 356, 676, 356, 676, 356, 676, 356, 676, 356, 676, 356, 676, 356, 676, 356, 676, 360, 676, 356, 676, 356, 676, 356, 676, 356, 680, 352, 680, 352, 680, 352, 680, 356, 680, 1060, 692, 356, 676, 356, 676, 356, 676, 356, 676, 340, 692, 356, 676, 348, 688, 356, 676, 356, 672, 1080, 672, 360, 676, 1076, 672, 360, 672, 360, 672, 364, 672, 360, 672, 1080, 672, 1084, 644, 388, 648, 384, 648, 1104, 648, 1108, 644, 388, 648};
uint16_t low21[] = {3868, 1356, 712, 1044, 708, 1044, 708, 324, 708, 324, 712, 320, 712, 1044, 708, 324, 708, 324, 712, 1044, 708, 1044, 712, 320, 684, 1072, 704, 328, 708, 324, 708, 1044, 708, 1044, 712, 324, 708, 1048, 704, 1048, 708, 324, 708, 324, 708, 1044, 708, 324, 708, 324, 712, 1048, 704, 328, 704, 328, 708, 324, 704, 328, 704, 328, 704, 328, 704, 328, 708, 328, 704, 328, 704, 340, 692, 328, 704, 344, 692, 324, 704, 344, 692, 340, 696, 340, 692, 340, 692, 1044, 708, 340, 692, 340, 692, 1060, 716, 316, 716, 320, 716, 1040, 712, 1040, 712, 320, 712, 320, 712, 320, 712, 320, 712, 320, 712, 324, 712, 320, 712, 1040, 712, 324, 708, 1044, 708, 324, 708, 324, 704, 328, 704, 332, 704, 328, 680, 1072, 704, 328, 704, 1048, 680, 356, 676, 356, 676, 356, 676, 356, 680, 356, 676, 356, 676, 356, 676, 356, 676, 356, 676, 356, 676, 356, 676, 356, 680, 356, 676, 356, 676, 356, 676, 340, 692, 356, 676, 356, 676, 356, 676, 356, 680, 1076, 676, 356, 676, 356, 676, 356, 676, 356, 676, 356, 676, 356, 672, 360, 676, 360, 672, 360, 672, 1080, 672, 360, 672, 1084, 668, 364, 648, 384, 644, 388, 648, 1108, 644, 388, 644, 1108, 644, 392, 640, 392, 640, 1112, 640, 1112, 644, 388, 644};
uint16_t low22[] = {3900, 1320, 716, 1040, 712, 1044, 732, 300, 708, 324, 708, 304, 752, 1020, 712, 320, 712, 308, 728, 1040, 712, 1044, 708, 324, 708, 1044, 708, 324, 708, 324, 708, 1048, 708, 1044, 712, 324, 708, 1044, 708, 1044, 712, 324, 708, 324, 708, 1044, 708, 324, 708, 324, 712, 1044, 708, 324, 708, 324, 708, 324, 708, 324, 708, 328, 704, 324, 708, 324, 712, 324, 708, 324, 708, 324, 708, 328, 704, 324, 708, 328, 704, 324, 708, 324, 712, 324, 708, 324, 708, 1048, 704, 328, 704, 344, 692, 1044, 708, 324, 708, 344, 692, 1044, 708, 1048, 704, 340, 692, 344, 688, 344, 692, 340, 712, 320, 716, 320, 712, 1040, 712, 320, 712, 320, 712, 1040, 712, 320, 712, 320, 712, 320, 712, 324, 712, 320, 712, 1044, 708, 324, 708, 1044, 708, 324, 708, 324, 704, 328, 704, 332, 680, 352, 680, 352, 676, 356, 676, 356, 676, 356, 676, 356, 676, 356, 676, 360, 676, 356, 676, 356, 676, 356, 676, 356, 676, 356, 676, 356, 676, 356, 676, 360, 680, 1060, 692, 356, 676, 356, 676, 356, 676, 356, 676, 356, 676, 340, 692, 356, 680, 340, 688, 360, 676, 1076, 676, 356, 676, 1076, 676, 356, 676, 356, 676, 360, 676, 356, 672, 360, 672, 1080, 676, 360, 668, 364, 668, 1084, 668, 1084, 656, 380, 648};
uint16_t low23[] = {3896, 1324, 680, 1080, 676, 1076, 676, 356, 672, 324, 712, 356, 676, 1076, 676, 356, 676, 356, 680, 1080, 676, 1076, 700, 316, 692, 1076, 680, 352, 680, 356, 704, 1048, 676, 1076, 680, 356, 680, 1072, 680, 1076, 676, 352, 680, 356, 676, 1076, 676, 356, 676, 356, 680, 1076, 680, 352, 680, 352, 676, 356, 704, 328, 704, 328, 704, 332, 676, 352, 684, 352, 688, 344, 704, 332, 700, 332, 700, 332, 700, 328, 708, 328, 700, 332, 704, 328, 680, 356, 680, 1072, 676, 356, 680, 352, 704, 1048, 704, 328, 704, 328, 708, 1048, 708, 1048, 700, 332, 704, 328, 704, 328, 704, 328, 708, 324, 708, 324, 708, 328, 708, 324, 704, 328, 704, 1048, 708, 328, 704, 328, 704, 328, 704, 344, 692, 340, 692, 1048, 708, 336, 696, 1060, 716, 316, 716, 316, 716, 316, 716, 320, 716, 316, 716, 316, 716, 316, 716, 316, 712, 320, 712, 320, 712, 320, 712, 324, 712, 320, 712, 320, 712, 320, 712, 320, 712, 320, 712, 320, 712, 320, 712, 324, 712, 1040, 708, 324, 708, 328, 704, 328, 704, 328, 704, 328, 704, 328, 704, 328, 708, 328, 704, 328, 704, 1032, 720, 328, 684, 1056, 696, 352, 676, 352, 680, 356, 680, 1076, 680, 1056, 692, 356, 680, 352, 676, 356, 676, 1076, 676, 1076, 680, 356, 744};
uint16_t low24[] = {3880, 1340, 712, 1048, 700, 1052, 700, 332, 700, 320, 716, 328, 700, 1052, 704, 328, 700, 332, 704, 1056, 676, 1076, 700, 332, 700, 1056, 696, 332, 704, 332, 700, 1052, 700, 1052, 704, 332, 700, 1052, 700, 1052, 700, 336, 700, 332, 700, 1052, 700, 332, 700, 332, 704, 1052, 700, 332, 700, 332, 704, 328, 700, 336, 676, 356, 700, 332, 700, 332, 700, 332, 700, 336, 696, 332, 680, 356, 700, 332, 676, 356, 700, 332, 700, 332, 704, 332, 700, 332, 700, 1052, 700, 332, 700, 332, 700, 1052, 704, 328, 704, 328, 704, 1056, 700, 1052, 680, 352, 704, 328, 700, 332, 704, 328, 704, 328, 704, 328, 704, 1052, 704, 1052, 700, 1052, 704, 328, 704, 328, 704, 328, 704, 328, 704, 348, 688, 328, 704, 1048, 704, 332, 704, 1048, 704, 348, 684, 344, 688, 344, 688, 344, 716, 320, 712, 320, 712, 320, 712, 320, 716, 316, 712, 320, 712, 320, 712, 324, 712, 320, 712, 320, 708, 324, 708, 324, 708, 324, 708, 324, 708, 324, 704, 332, 704, 1048, 704, 328, 680, 352, 680, 352, 676, 356, 676, 356, 676, 356, 676, 360, 676, 356, 676, 360, 672, 1064, 688, 360, 672, 1068, 684, 360, 672, 360, 676, 360, 676, 356, 676, 1064, 688, 356, 676, 344, 688, 344, 688, 1064, 688, 1064, 692, 344, 748};
uint16_t low25[] = {3876, 1344, 676, 1084, 672, 1096, 652, 364, 696, 352, 656, 360, 672, 1080, 672, 376, 680, 332, 680, 1084, 692, 1060, 672, 360, 672, 1080, 696, 348, 664, 372, 660, 1080, 672, 1080, 676, 376, 656, 1080, 700, 1052, 676, 372, 684, 352, 680, 1056, 700, 344, 684, 352, 688, 1068, 684, 348, 684, 348, 684, 348, 684, 344, 688, 348, 684, 348, 688, 348, 688, 344, 688, 344, 688, 344, 688, 344, 692, 340, 692, 340, 692, 340, 692, 344, 716, 316, 716, 316, 720, 1036, 688, 344, 716, 316, 716, 1036, 716, 316, 716, 320, 716, 1036, 716, 1040, 716, 312, 720, 316, 716, 316, 716, 316, 716, 316, 716, 320, 716, 316, 716, 1036, 716, 1036, 716, 316, 720, 312, 720, 312, 720, 312, 720, 316, 720, 316, 716, 1036, 716, 316, 716, 1036, 716, 316, 716, 316, 716, 316, 716, 320, 716, 316, 716, 316, 716, 316, 716, 316, 716, 316, 716, 316, 716, 316, 716, 320, 716, 316, 712, 320, 712, 320, 712, 320, 712, 320, 712, 320, 712, 320, 712, 324, 712, 1028, 720, 324, 708, 328, 704, 328, 704, 328, 704, 328, 680, 352, 680, 356, 676, 356, 676, 356, 676, 1060, 696, 352, 676, 1064, 692, 352, 680, 352, 680, 356, 676, 1064, 692, 340, 692, 340, 692, 340, 688, 344, 692, 1064, 688, 1064, 688, 344, 724};
uint16_t med17[] = {3836, 1396, 688, 1068, 704, 1052, 700, 248, 756, 372, 688, 348, 684, 1052, 696, 336, 704, 348, 680, 1056, 700, 1056, 700, 344, 684, 1056, 700, 332, 700, 336, 696, 1056, 700, 1052, 704, 344, 684, 1056, 700, 1068, 684, 336, 700, 332, 692, 1060, 700, 324, 704, 336, 696, 1060, 700, 332, 696, 336, 700, 332, 700, 336, 692, 352, 676, 356, 684, 332, 700, 336, 696, 340, 692, 336, 696, 336, 696, 336, 696, 336, 692, 344, 692, 356, 680, 352, 680, 336, 696, 1060, 688, 344, 692, 340, 696, 1056, 668, 364, 692, 356, 684, 1056, 692, 1064, 692, 336, 696, 340, 692, 340, 688, 344, 672, 360, 692, 344, 692, 340, 696, 1056, 692, 1060, 692, 1064, 688, 344, 692, 340, 692, 340, 688, 344, 668, 1088, 692, 1060, 692, 340, 692, 1064, 692, 340, 688, 344, 688, 344, 688, 344, 692, 344, 664, 364, 668, 368, 664, 368, 688, 344, 684, 348, 688, 344, 688, 344, 692, 344, 688, 344, 684, 348, 660, 372, 660, 372, 684, 348, 660, 372, 660, 372, 664, 1092, 660, 372, 660, 376, 656, 372, 684, 348, 660, 372, 660, 372, 660, 376, 660, 372, 660, 372, 660, 408, 624, 376, 656, 1096, 656, 412, 620, 412, 620, 392, 644, 412, 620, 1132, 624, 1128, 624, 408, 624, 412, 620, 1132, 620, 1132, 620, 416, 620};
uint16_t med18[] = {3876, 1344, 672, 1084, 668, 1084, 668, 364, 668, 368, 668, 360, 672, 1084, 668, 364, 672, 360, 676, 1080, 672, 1084, 668, 364, 672, 1080, 700, 332, 700, 348, 688, 1064, 692, 1064, 692, 340, 716, 1040, 716, 1036, 716, 316, 716, 316, 716, 1036, 720, 312, 720, 316, 720, 1036, 712, 316, 716, 316, 720, 312, 720, 312, 720, 312, 716, 320, 716, 320, 712, 320, 712, 320, 712, 320, 712, 320, 712, 320, 712, 320, 712, 320, 712, 324, 712, 320, 708, 324, 708, 1028, 724, 324, 708, 324, 708, 1032, 720, 324, 708, 328, 684, 1056, 696, 1056, 692, 356, 680, 336, 692, 340, 692, 344, 688, 344, 688, 344, 692, 1064, 688, 344, 692, 1060, 692, 1060, 692, 340, 692, 340, 692, 340, 692, 344, 692, 1064, 688, 1064, 688, 344, 688, 1064, 688, 344, 688, 344, 688, 344, 688, 348, 688, 344, 688, 344, 688, 344, 664, 372, 684, 348, 660, 372, 660, 372, 660, 372, 684, 352, 660, 372, 660, 372, 660, 372, 656, 412, 620, 412, 620, 412, 620, 392, 644, 1132, 620, 412, 620, 412, 620, 412, 620, 412, 620, 412, 620, 412, 620, 396, 640, 412, 620, 412, 620, 412, 620, 416, 616, 1136, 616, 416, 616, 416, 616, 420, 616, 1136, 616, 416, 616, 1136, 616, 420, 612, 420, 612, 1140, 616, 1140, 608, 424, 636};
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
void loop()
{
  client.loop();
  if (!client.connected())
  {
    Serial.println("Reconnecting");
    connect();
  }

  // publish a message roughly every 10 second.
  if (millis() - lastMillis > 10000)
  {
    lastMillis = millis();

    sensors.requestTemperatures();

    temperatureC = sensors.getTempCByIndex(0);
    // Serial.println(temperatureC);

    lcd_print(temperatureC);

    if (temperatureC < 0 || temperatureC > 28)
    {
      digitalWrite(siren, HIGH);
    }

    String temp_str = String(temperatureC);

    String payload_str = nodeId + "," + temp_str + "," + location;
    char payload[100];

    payload_str.toCharArray(payload, payload_str.length() + 1);

    Serial.println(payload);
    Serial.println(temp);

    if (client.publish("/nodes/temp/1", payload))
    {
      Serial.println("Sucess");
      Serial.println(temperatureC);
      Serial.println("ºC");
    }
    else
    {
      Serial.println("Failed Publish");
    }
    Serial.println("Published");
  }
  // client.loop();
}

/**
 * @brief Function will check if the MQTT is connected, if it is not connected
 *        it will first try to connect with internet using LAN module and then
 *        again try to reconnect.
 */
void connect()
{
  Serial.print("connecting...");

  while (!client.connect("serverESP32", "<USERNAME>", "<PASSWORD>"))
  {
    Serial.print(".");
    Ethernet.init(5);
    if (Ethernet.begin(mac) == 0)
    {
      Serial.println("Failed");
    }
    Serial.print("IP Address   : ");
    Serial.println(Ethernet.localIP());
  }

  Serial.println("\nconnected!");

  client.subscribe("/nodes/command/1");
}

/**
 * @brief Function is executed when a message arrives on subscribed topic
 *
 * @param topic   Topic on which message has arrived
 * @param payload Message which has arrived
 * @param length  Length of the message
 */
void callback(char *topic, byte *payload, unsigned int length)
{
  Serial.print("Message arrived [");
  Serial.print(topic);
  Serial.print("] ");

  String cmd = "";

  for (int i = 0; i < length; i++)
  {
    Serial.print((char)payload[i]);
    cmd += (char)payload[i];
  }
  Serial.println();

  Serial.println(cmd);

  ACtemp = cmd;

  command(cmd);
}

/**
 * @brief Function will send command based in the recieved mqtt message
 *
 * @param command commands which needs to be executed. Ex: '17l' to set AC at 17 with low fanspeed
 */
void command(String command)
{
  int cmd_number = 0;

  for (int i = 0; i < sizeof(mapping) / sizeof(dict); i++)
  {
    if (command == mapping[i].temp)
    {
      cmd_number = mapping[i].num;
    }
  }

  Serial.println(cmd_number);

  switch (cmd_number)
  {
  case 0:
    //
  case 1:
    irsend.sendRaw(off, sizeof(off) / sizeof(off[0]), 38);
    break;
  case 2:
    irsend.sendRaw(low17, sizeof(low17) / sizeof(low17[0]), 38);
  case 3:
    irsend.sendRaw(low18, sizeof(low18) / sizeof(low18[0]), 38);
  case 4:
    irsend.sendRaw(low19, sizeof(low19) / sizeof(low19[0]), 38);
  case 5:
    irsend.sendRaw(low20, sizeof(low20) / sizeof(low20[0]), 38);
  case 6:
    irsend.sendRaw(low21, sizeof(low21) / sizeof(low21[0]), 38);
  case 7:
    irsend.sendRaw(low22, sizeof(low22) / sizeof(low22[0]), 38);
  case 8:
    irsend.sendRaw(low23, sizeof(low23) / sizeof(low23[0]), 38);
  case 9:
    irsend.sendRaw(low24, sizeof(low24) / sizeof(low24[0]), 38);
  case 10:
    irsend.sendRaw(low25, sizeof(low25) / sizeof(low25[0]), 38);
  case 11:
    irsend.sendRaw(med17, sizeof(med17) / sizeof(med17[0]), 38);
  case 12:
    irsend.sendRaw(med18, sizeof(med18) / sizeof(med18[0]), 38);
  case 13:
    irsend.sendRaw(med19, sizeof(med19) / sizeof(med19[0]), 38);
  case 14:
    irsend.sendRaw(med20, sizeof(med20) / sizeof(med20[0]), 38);
  case 15:
    irsend.sendRaw(med21, sizeof(med21) / sizeof(med21[0]), 38);
  case 16:
    irsend.sendRaw(med22, sizeof(med22) / sizeof(med22[0]), 38);
  case 17:
    irsend.sendRaw(med23, sizeof(med23) / sizeof(med23[0]), 38);
  case 18:
    irsend.sendRaw(med24, sizeof(med24) / sizeof(med24[0]), 38);
  case 19:
    irsend.sendRaw(med25, sizeof(med25) / sizeof(med25[0]), 38);
  case 20:
    irsend.sendRaw(high17, sizeof(high17) / sizeof(high17[0]), 38);
  case 21:
    irsend.sendRaw(high18, sizeof(high18) / sizeof(high18[0]), 38);
  case 22:
    irsend.sendRaw(high19, sizeof(high19) / sizeof(high19[0]), 38);
  case 23:
    irsend.sendRaw(high20, sizeof(high20) / sizeof(high20[0]), 38);
  case 24:
    irsend.sendRaw(high21, sizeof(high21) / sizeof(high21[0]), 38);
  case 25:
    irsend.sendRaw(high22, sizeof(high22) / sizeof(high22[0]), 38);
  case 26:
    irsend.sendRaw(high23, sizeof(high23) / sizeof(high23[0]), 38);
  case 27:
    irsend.sendRaw(high24, sizeof(high24) / sizeof(high24[0]), 38);
  case 28:
    irsend.sendRaw(high25, sizeof(high25) / sizeof(high25[0]), 38);
  default:
    break;
  }
}

void lcd_print(float roomTemp)
{
  lcd.clear();
  lcd.setCursor(0, 1);
  lcd.print("IP: ");
  
  lcd.print(IP);

  lcd.setCursor(0, 0);
  lcd.print("Room ");
  lcd.write(1);
  lcd.print(":");
  lcd.print(roomTemp);
  lcd.write(0);
  lcd.print("C");

  String acTemp = "";
  String acCmd = "";

  acTemp += ACtemp[0];
  acTemp += ACtemp[1];

  acCmd += ACtemp[2];

  lcd.setCursor(0, 3);
  lcd.print("AC   ");
  lcd.write(1);
  lcd.print(":");
  lcd.print(acTemp);
  lcd.write(0);
  lcd.print("C");

  lcd.setCursor(0, 2);
  lcd.print("AC Mode:");
  if (acCmd == "l")
  {
    lcd.print("LOW");
  }
  else if (acCmd == "m")
  {
    lcd.print("MEDIUM");
  }
  else if (acCmd == "h")
  {
    lcd.print("HIGH");
  }
}

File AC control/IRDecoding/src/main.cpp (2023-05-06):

#include <Arduino.h>
#include <IRLibSendBase.h> //We need the base code
#include <IRLib_HashRaw.h> //Only use raw sender

IRsendRaw mySender;

#define maxLen 800
#define rxPinIR 2
int lengths = 0;

int n = 0;
volatile unsigned int irBuffer[maxLen];
volatile unsigned int x = 0;

void setup()
{

  int m;
  Serial.begin(115200);

  pinMode(LED_BUILTIN, OUTPUT);
  pinMode(5, OUTPUT);
  pinMode(4, OUTPUT);
  attachInterrupt(digitalPinToInterrupt(rxPinIR), rxIR_Interrupt_Handler, CHANGE);
  Serial.println(F("INSTRUCTIONS: "));
  Serial.println(F("1. There are two buttons on the PCB: a right button to start decoding and a left button to verify the decoded signal."));
  Serial.println(F("2. To start decoding, press the right button on the PCB once."));
  Serial.println(F("3. Use the remote control of your AC or device to send the signal that you want to decode."));
  Serial.println(F("4. The decoded signal will appear on the monitor as array elements. Once all the array elements have appeared, the decoding process will automatically stop."));
  Serial.println(F("5. To verify if the signal is working correctly, press and hold the left button on the PCB for a 10 seconds"));
  Serial.println(F("6. If AC beeps the signal decoded is 'ok' Copy all elemets and name it accordingly for further setup, otherwise deode the same signal again"));
  Serial.println(F("7. Remember to decode the signal for each temperature with different fan speed. For example, for temperature 17, you will need to decode three signals: temp-17::fan-high, temp-17::fan:medium, and temp-17::fan-low."));
  Serial.println(F("8. now to start decoding press right button."));
  Serial.println(F(""));
  Serial.println(F(""));
}

void loop()
{

  if (digitalRead(5) == HIGH)
    n = 1;

  if (n == 1)
  {
    Serial.println(F("Press button from AC remote(once only)"));
    delay(2000);
  }

  if (digitalRead(4) == HIGH)
  {
    n = 0;
    Serial.print(F("sending__signal--------"));
    mySender.send(irBuffer, lengths, 38);

    delay(1000);
  }

  if (x)
  {
    digitalWrite(LED_BUILTIN, HIGH);
    Serial.println();
    Serial.print(F("Raw: ("));
    Serial.print(x - 1);
    Serial.print(F(")"));
    lengths = (x - 1);
    detachInterrupt(digitalPinToInterrupt(rxPinIR));

    for (int i = 1; i < x; i++)
    {
      irBuffer[i - 1] = irBuffer[i] - irBuffer[i - 1];
      Serial.print(irBuffer[i - 1]);
      if (i != x - 1)
        Serial.print(F(", "));
    }

    x = 0;
    Serial.println(F(""));
    digitalWrite(LED_BUILTIN, LOW);                                                  // end of visual indicator, for this time
    attachInterrupt(digitalPinToInterrupt(rxPinIR), rxIR_Interrupt_Handler, CHANGE); // re-enable ISR for receiving IR signal
    n = 0;
  }
}

void rxIR_Interrupt_Handler()
{
  if (n == 1)
  {
    if (x > maxLen)
      return;                 // ignore if irBuffer is already full
    irBuffer[x++] = micros(); // just continually record the time-stamp of signal transitions
  }
}
